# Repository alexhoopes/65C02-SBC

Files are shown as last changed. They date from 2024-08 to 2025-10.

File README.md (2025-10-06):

# 65C02-SBC

My first PCB design inspired by Ben Eater's 6502 YouTube series

KiCad and Gerber files are added - looking for community support in helping make sure I'm not missing anything





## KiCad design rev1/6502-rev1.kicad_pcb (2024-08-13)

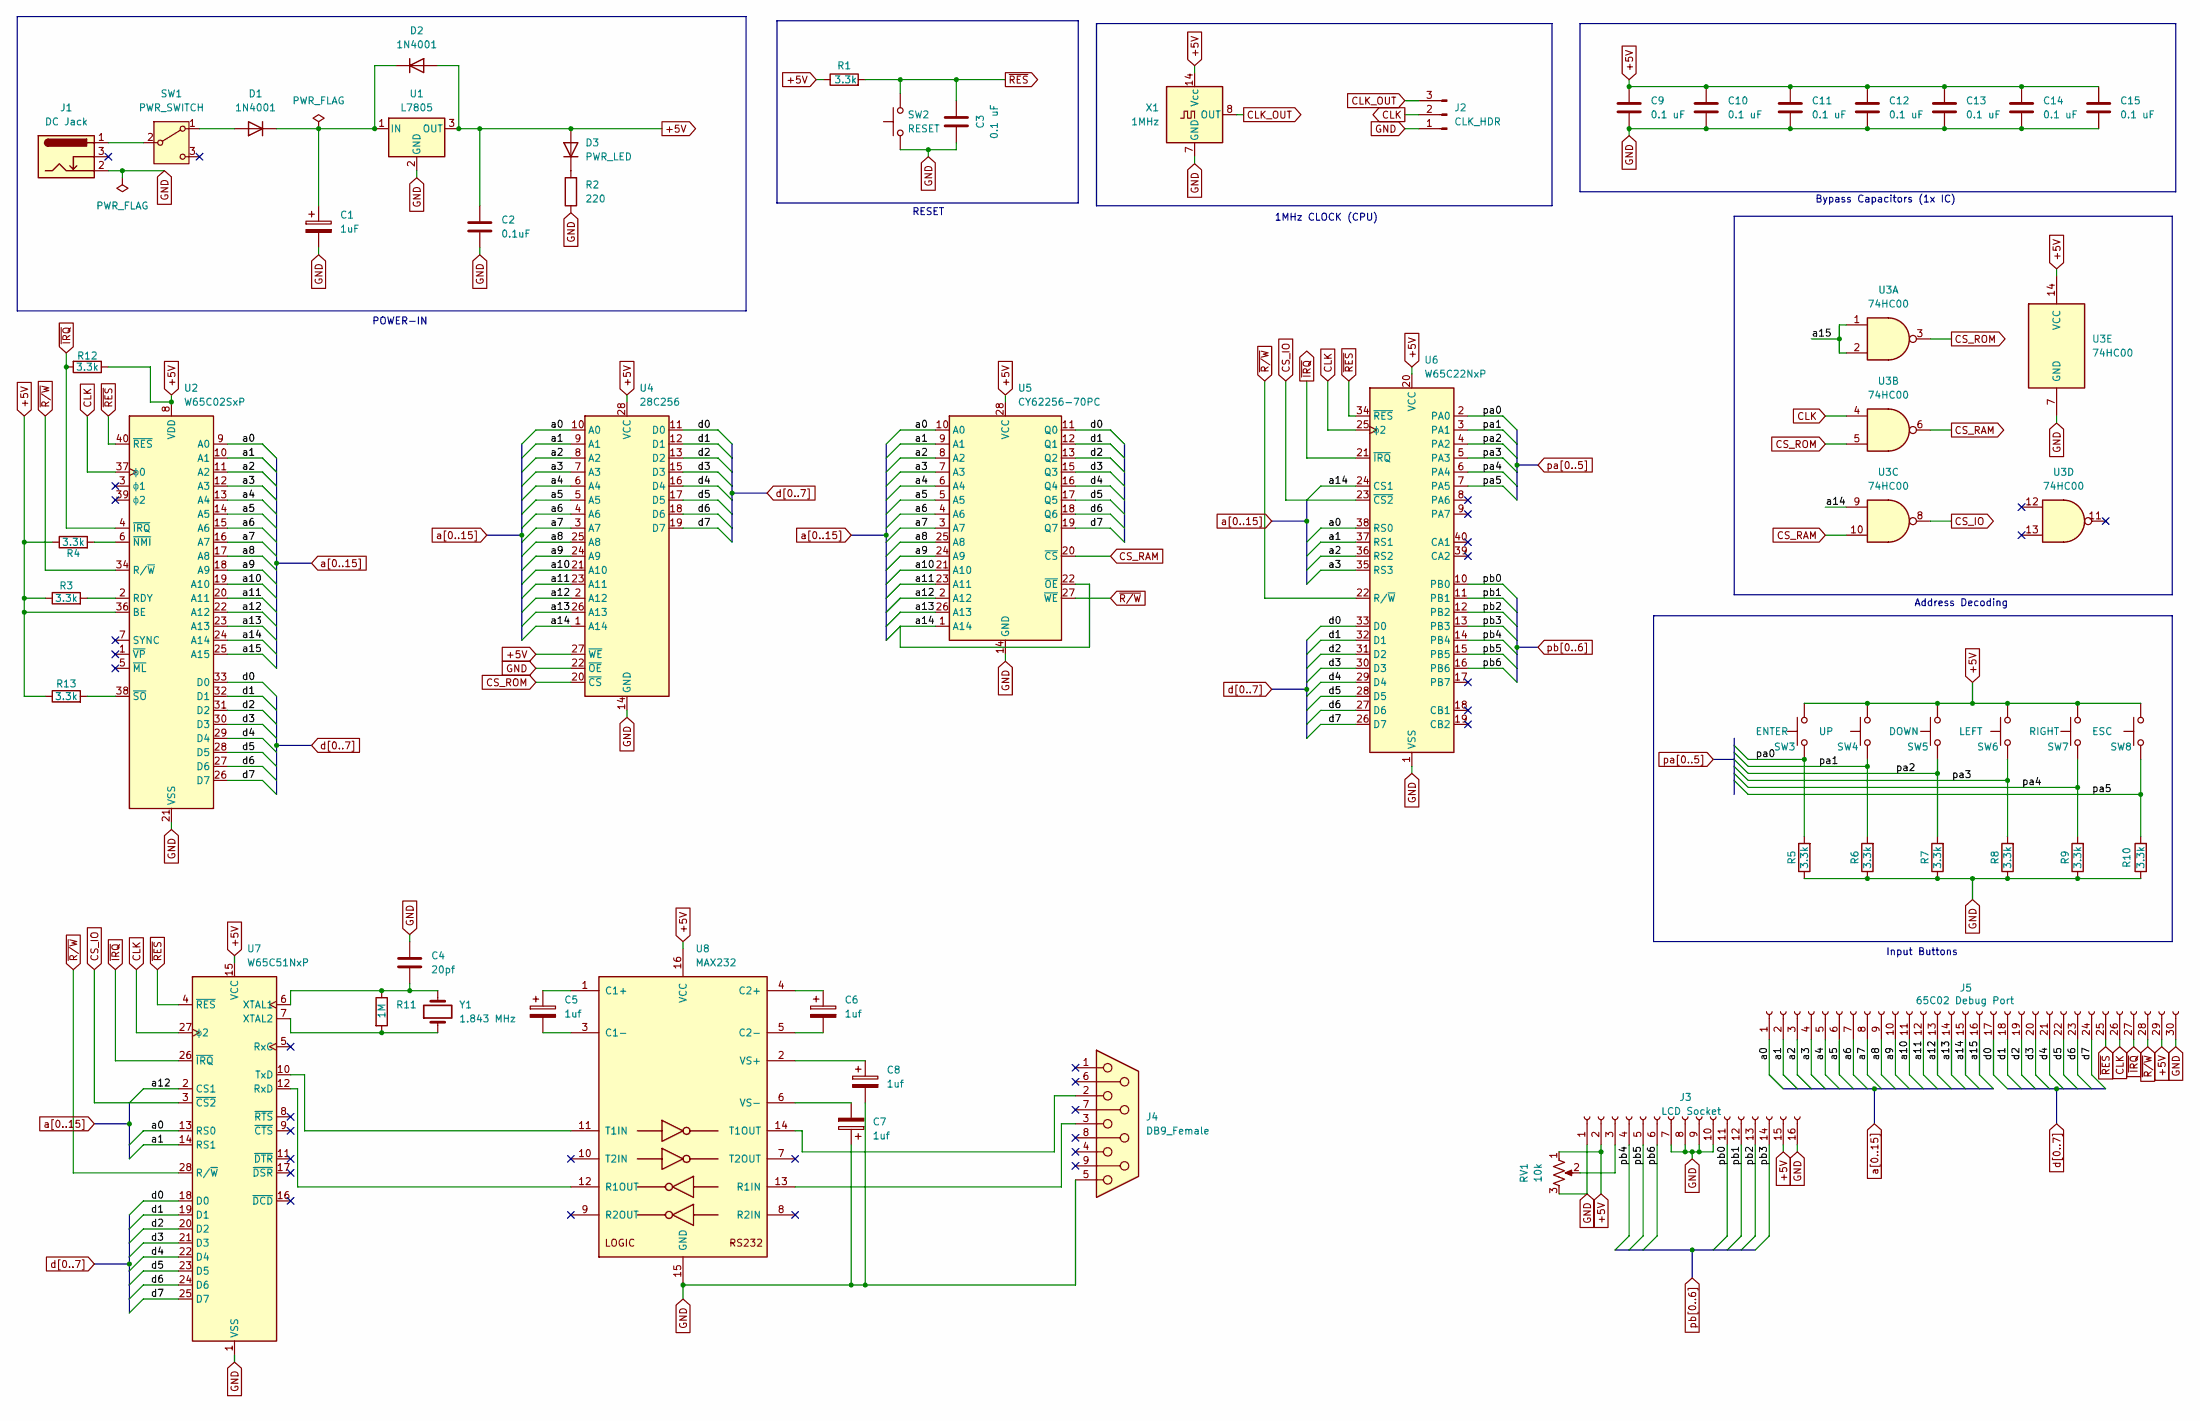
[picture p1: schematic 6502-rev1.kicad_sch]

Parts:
C1: 1uF; CAPPRD200W55D500H1220
C2: 0.1uF; C322C104K1R5TA
C3, C9, C10, C11, C12, C13, C14, C15: 0.1 uF; C322C104K1R5TA
C4: 20pf; C322C104K1R5TA
C5, C6, C7, C8: 1uf; CAPPRD200W55D500H1220
D1, D2: 1N4001; DIOAD1530W84L490D260
D3: PWR_LED; 151051BS04000
J1: DC Jack; PJ050AH
J2: CLK_HDR; PinHeader_1x03_P2.54mm_Vertical
J3: LCD Socket; RHDR16W82P0X254_1X16_4114X250X865P
J4: DB9_Female; 09661127600
J5: 65C02 Debug Port; SSW-115-XX-YYY-D
R1, R3, R4, R5, R6, R7, R8, R9, R10, R12, R13: 3.3k; R_Axial_DIN0207_L6.3mm_D2.5mm_P7.62mm_Horizontal
R2: 220; R_Axial_DIN0207_L6.3mm_D2.5mm_P7.62mm_Horizontal
R11: 1M; R_Axial_DIN0204_L3.6mm_D1.6mm_P7.62mm_Horizontal
RV1: 10k; TRIM_PTN06-D10HB20-H
SW1: PWR_SWITCH; SLW12768644AD
SW2: RESET; SW_PUSH_6mm
SW3: ENTER; SW_PUSH_6mm
SW4: UP; SW_PUSH_6mm
SW5: DOWN; SW_PUSH_6mm
SW6: LEFT; SW_PUSH_6mm
SW7: RIGHT; SW_PUSH_6mm
SW8: ESC; SW_PUSH_6mm
U1: L7805; TO255P460X1020X2008-3P
U2: W65C02SxP; DIP-40_W15.24mm_Socket
U3: 74HC00; DIP-14_W7.62mm_Socket
U4: 28C256; 28655410
U5: CY62256-70PC; DIP-28_W15.24mm_Socket
U6: W65C22NxP; DIP-40_W15.24mm_Socket
U7: W65C51NxP; DIP-28_W15.24mm_Socket
U8: MAX232; DIP-16_W7.62mm_Socket
X1: 1MHz; Oscillator_DIP-14
Y1: 1.843 MHz; XTAL_ECS-18-13-1X

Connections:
+5V: C2.1, C9.1, C10.1, C11.1, C12.1, C13.1, C14.1, C15.1, D2.2 (A), D3.2 (A), J3.2, J3.15, J5.29, R1.1, R3.1, R4.1, R12.1, R13.1, RV1.1, SW3.2, SW4.2, SW5.2, SW6.2, SW7.2, SW8.2, U1.3 (OUT), U2.8 (VDD), U2.36 (BE), U3.14 (VCC), U4.27 (~WE), U4.28 (VCC), U5.28 (VCC), U6.20 (VCC), U7.15 (VCC), U8.16 (VCC), X1.14 (Vcc)
CLK: J2.2, J5.26, U2.37 (ϕ0), U3.4, U6.25 (ϕ2), U7.27 (ϕ2)
CLK_OUT: J2.3, X1.8 (OUT)
CS_IO: U3.8, U6.23 (~CS2), U7.3 (~CS2)
CS_RAM: U3.6, U3.10, U5.20 (~CS)
CS_ROM: U3.3, U3.5, U4.20 (~CS)
GND: C1.2, C2.2, C3.1, C4.1, C7.1, C8.2, C9.2, C10.2, C11.2, C12.2, C13.2, C14.2, C15.2, J1.2, J2.1, J3.1, J3.7, J3.8, J3.9, J3.10, J3.16, J4.5, J5.30, R2.1, R5.1, R6.1, R7.1, R8.1, R9.1, R10.1, RV1.3, SW2.1, U1.2 (GND), U2.21 (VSS), U3.7 (GND), U4.14 (GND), U4.22 (~OE), U5.14 (GND), U6.1 (VSS), U7.1 (VSS), U8.15 (GND), X1.7 (GND)
unnamed: D1.2 (A), SW1.1 (A)
unnamed: C1.1, D1.1 (K), D2.1 (K), U1.1 (IN)
unnamed: D3.1 (K), R2.2
unnamed: J3.3, RV1.2
unnamed: J1.1, SW1.2 (B)
unnamed: R3.2, U2.2 (RDY)
unnamed: R4.2, U2.6 (~NMI)
unnamed: R13.2, U2.38 (~SO)
unnamed: U7.12 (RxD), U8.12 (R1OUT)
unnamed: U7.10 (TxD), U8.11 (T1IN)
unnamed: C4.2, R11.1, U7.6 (XTAL1), Y1.2
unnamed: R11.2, U7.7 (XTAL2), Y1.1
unnamed: C5.1, U8.1 (C1+)
unnamed: C5.2, U8.3 (C1-)
unnamed: C6.1, U8.4 (C2+)
unnamed: C6.2, U8.5 (C2-)
unnamed: J4.3, U8.13 (R1IN)
unnamed: J4.2, U8.14 (T1OUT)
unnamed: C8.1, U8.2 (VS+)
unnamed: C7.2, U8.6 (VS-)
a0: J5.1, U2.9 (A0), U4.10 (A0), U5.10 (A0), U6.38 (RS0), U7.13 (RS0)
a1: J5.2, U2.10 (A1), U4.9 (A1), U5.9 (A1), U6.37 (RS1), U7.14 (RS1)
a2: J5.3, U2.11 (A2), U4.8 (A2), U5.8 (A2), U6.36 (RS2)
a3: J5.4, U2.12 (A3), U4.7 (A3), U5.7 (A3), U6.35 (RS3)
a4: J5.5, U2.13 (A4), U4.6 (A4), U5.6 (A4)
a5: J5.6, U2.14 (A5), U4.5 (A5), U5.5 (A5)
a6: J5.7, U2.15 (A6), U4.4 (A6), U5.4 (A6)
a7: J5.8, U2.16 (A7), U4.3 (A7), U5.3 (A7)
a8: J5.9, U2.17 (A8), U4.25 (A8), U5.25 (A8)
a9: J5.10, U2.18 (A9), U4.24 (A9), U5.24 (A9)
a10: J5.11, U2.19 (A10), U4.21 (A10), U5.21 (A10)
a11: J5.12, U2.20 (A11), U4.23 (A11), U5.23 (A11)
a12: J5.13, U2.22 (A12), U4.2 (A12), U5.2 (A12), U7.2 (CS1)
a13: J5.14, U2.23 (A13), U4.26 (A13), U5.26 (A13)
a14: J5.15, U2.24 (A14), U3.9, U4.1 (A14), U5.1 (A14), U5.22 (~OE), U6.24 (CS1)
a15: J5.16, U2.25 (A15), U3.1, U3.2
d0: J5.17, U2.33 (D0), U4.11 (D0), U5.11 (Q0), U6.33 (D0), U7.18 (D0)
d1: J5.18, U2.32 (D1), U4.12 (D1), U5.12 (Q1), U6.32 (D1), U7.19 (D1)
d2: J5.19, U2.31 (D2), U4.13 (D2), U5.13 (Q2), U6.31 (D2), U7.20 (D2)
d3: J5.20, U2.30 (D3), U4.15 (D3), U5.15 (Q3), U6.30 (D3), U7.21 (D3)
d4: J5.21, U2.29 (D4), U4.16 (D4), U5.16 (Q4), U6.29 (D4), U7.22 (D4)
d5: J5.22, U2.28 (D5), U4.17 (D5), U5.17 (Q5), U6.28 (D5), U7.23 (D5)
d6: J5.23, U2.27 (D6), U4.18 (D6), U5.18 (Q6), U6.27 (D6), U7.24 (D6)
d7: J5.24, U2.26 (D7), U4.19 (D7), U5.19 (Q7), U6.26 (D7), U7.25 (D7)
pa0: R5.2, SW3.1, U6.2 (PA0)
pa1: R6.2, SW4.1, U6.3 (PA1)
pa2: R7.2, SW5.1, U6.4 (PA2)
pa3: R8.2, SW6.1, U6.5 (PA3)
pa4: R9.2, SW7.1, U6.6 (PA4)
pa5: R10.2, SW8.1, U6.7 (PA5)
pb0: J3.11, U6.10 (PB0)
pb1: J3.12, U6.11 (PB1)
pb2: J3.13, U6.12 (PB2)
pb3: J3.14, U6.13 (PB3)
pb4: J3.4, U6.14 (PB4)
pb5: J3.5, U6.15 (PB5)
pb6: J3.6, U6.16 (PB6)
~IRQ: J5.27, R12.2, U2.4 (~IRQ), U6.21 (~IRQ), U7.26 (~IRQ)
~RES: C3.2, J5.25, R1.2, SW2.2, U2.40 (~RES), U6.34 (~RES), U7.4 (~RES)
~R/W: J5.28, U2.34 (R/~W), U5.27 (~WE), U6.22 (R/~W), U7.28 (R/~W)

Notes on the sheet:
RESET
Address Decoding
Input Buttons
1MHz CLOCK (CPU)
POWER-IN
Bypass Capacitors (1x IC)

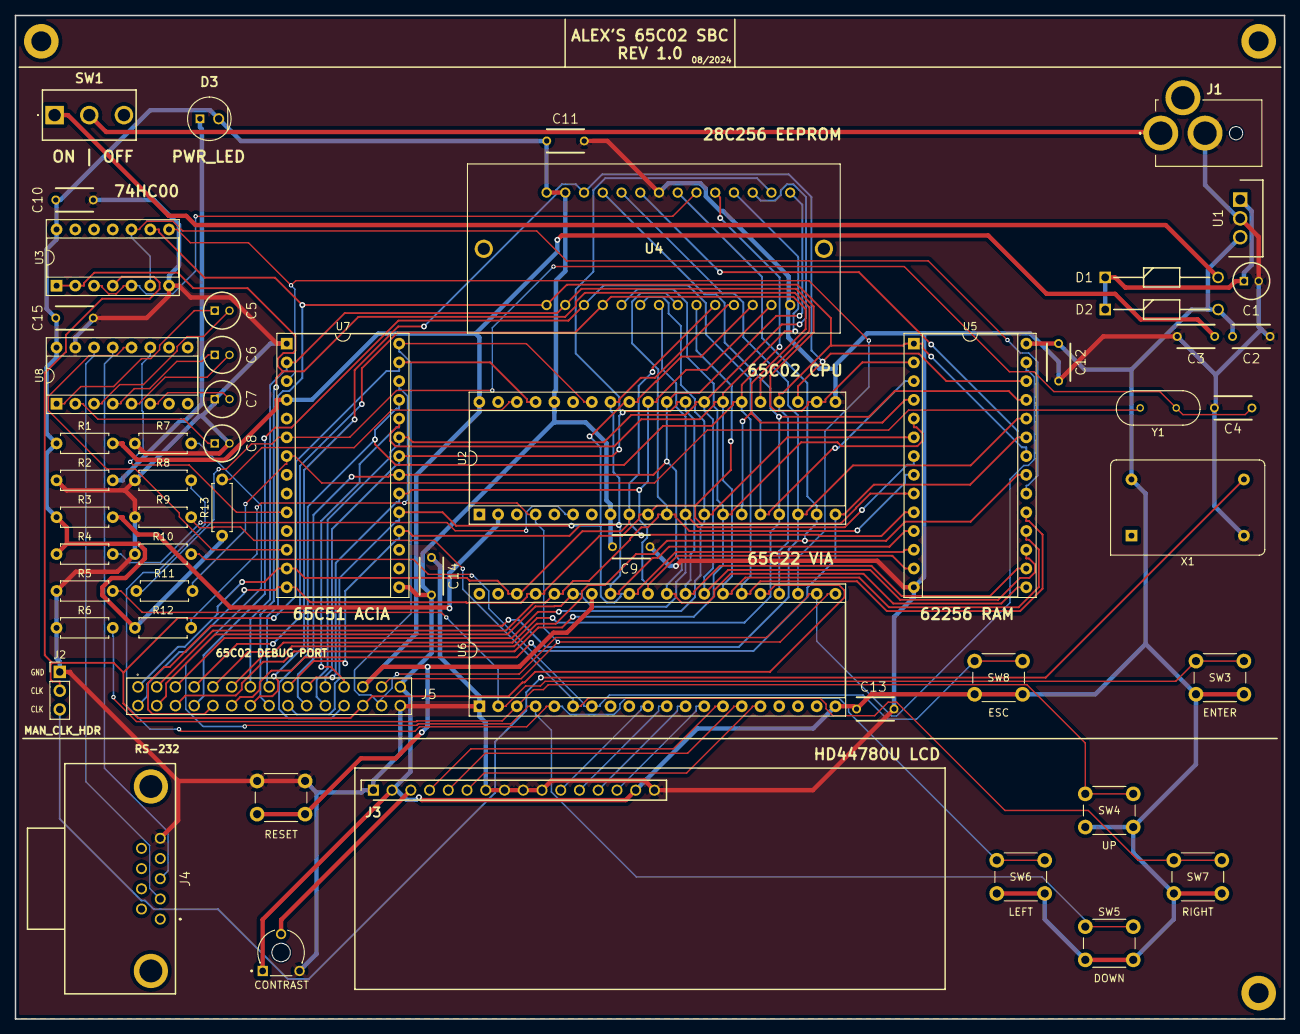
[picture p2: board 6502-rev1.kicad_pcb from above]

Board: 2 copper layers, 172.0 x 136.0 mm, 58 parts (0 on the bottom side), 67 nets.

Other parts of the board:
MH3, MH4, MH5: MountingHole_2.7mm_M2.5_DIN965_Pad
